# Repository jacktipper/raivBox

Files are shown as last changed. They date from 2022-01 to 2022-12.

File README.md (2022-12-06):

# raivBox

The raivBox is a standalone neural audio synthesis device based on Google Magenta's [DDSP](https://github.com/magenta/ddsp), with an [NVIDIA Jetson Nano 2GB](https://www.nvidia.com/en-us/autonomous-machines/embedded-systems/jetson-nano/education-projects/) embedded development board at its core. This entire project is designed to be as affordable and replicable as possible, while still offering a robust neural synthesis experience outside of a traditional laptop/desktop computer environment. 

[3D Model](https://a360.co/3CzAN5L)

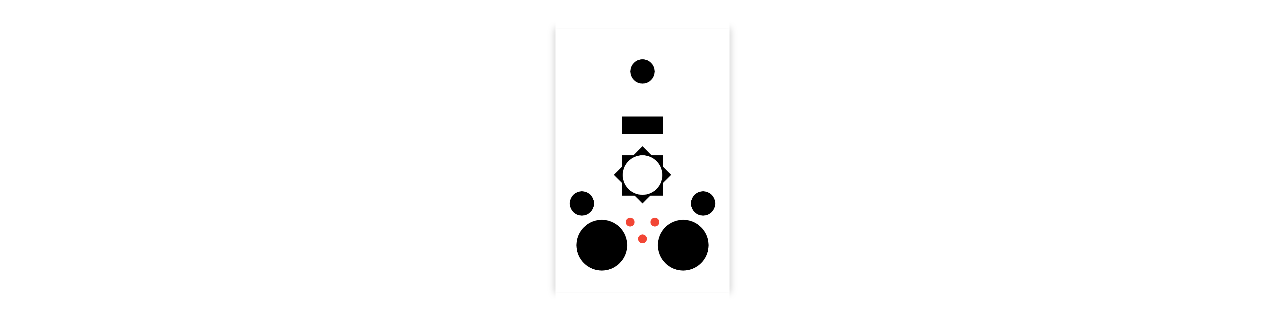
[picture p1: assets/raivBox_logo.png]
raivBox logo


## Abstract

Recent advances in deep learning-based audio creation are fueling the rise of a new approach to sound design: neural synthesis. Until now, robust neural synthesizers for musical sounds have been relegated to traditional desktop and cloud-based computing environments. Hosting these generative systems on low-cost devices will broaden offline and untethered access to this fledgling technology, helping to make way for a new era of modular music and audio experimentation. In this thesis, the implementation of neural waveform synthesis on a resource-limited embedded development platform is explored using a modified version of Google Magenta’s Differentiable Digital Signal Processing (DDSP) timbre transfer pipeline on an Nvidia Jetson Nano 2GB embedded prototyping board. Timbre transfer is a type of neural synthesis achieved by extracting audio features from an input signal and utilizing those data to generate a new waveform in the target timbre. This project introduces the raivBox: a functional neural synthesizer in the form of an affordable, standalone hardware product. It features a physical control interface that provides responsive audio input and output, a selection of five neural timbre models to choose from, and a straightforward user experience. The reworked neural synthesis pipeline demonstrates a significant processing latency reduction when compared with its predecessor, while maintaining similar sonic outputs. Qualitative research data indicate that users find the raivBox to be both intuitive and fun to interact with, and also suggest that it is perceived to be a valuable new tool for music creation and sound design. As this project is designed to be readily replicable by end users, the raivBox source code, build instructions, print files, and a variety of audio examples are all publicly available via its GitHub repository.

## Getting Started

Please refer to `assets/raivBox_thesis.pdf` for the full documentation of this project. See the *Methodology* section for detailed build instructions.

The `raivBox/` folder contains all of the important files and scripts.

To initialize a blank NVIDIA Jetson Nano 2GB operating system img with the required dependencies for this project, first flash the OS onto the Jetson, complete the basic user setup wizard, and then follow the instructions in the header of `raivBox/raivShell.sh`.

In later versions of this repository, a fully-baked OS img file will be provided. Flashing this img to a Jetson Nano 2GB's SD card will pre-load all of the software needed for this project.

The core DDSP synthesis loop is in `raivBox/synth.py`.

Useful system stats and UI animations are displayed via `raivBox/stats.py`.

All of the additional python files in this repository facilitate hardware-software interaction on the physical raivBox device.

In addition to the master's thesis document, the `assets/` folder contains the custom printed circuit board (PCB) zip file and the three stl files needed to 3D-print the raivBox housing components, as well as a few pictures and renders.

#

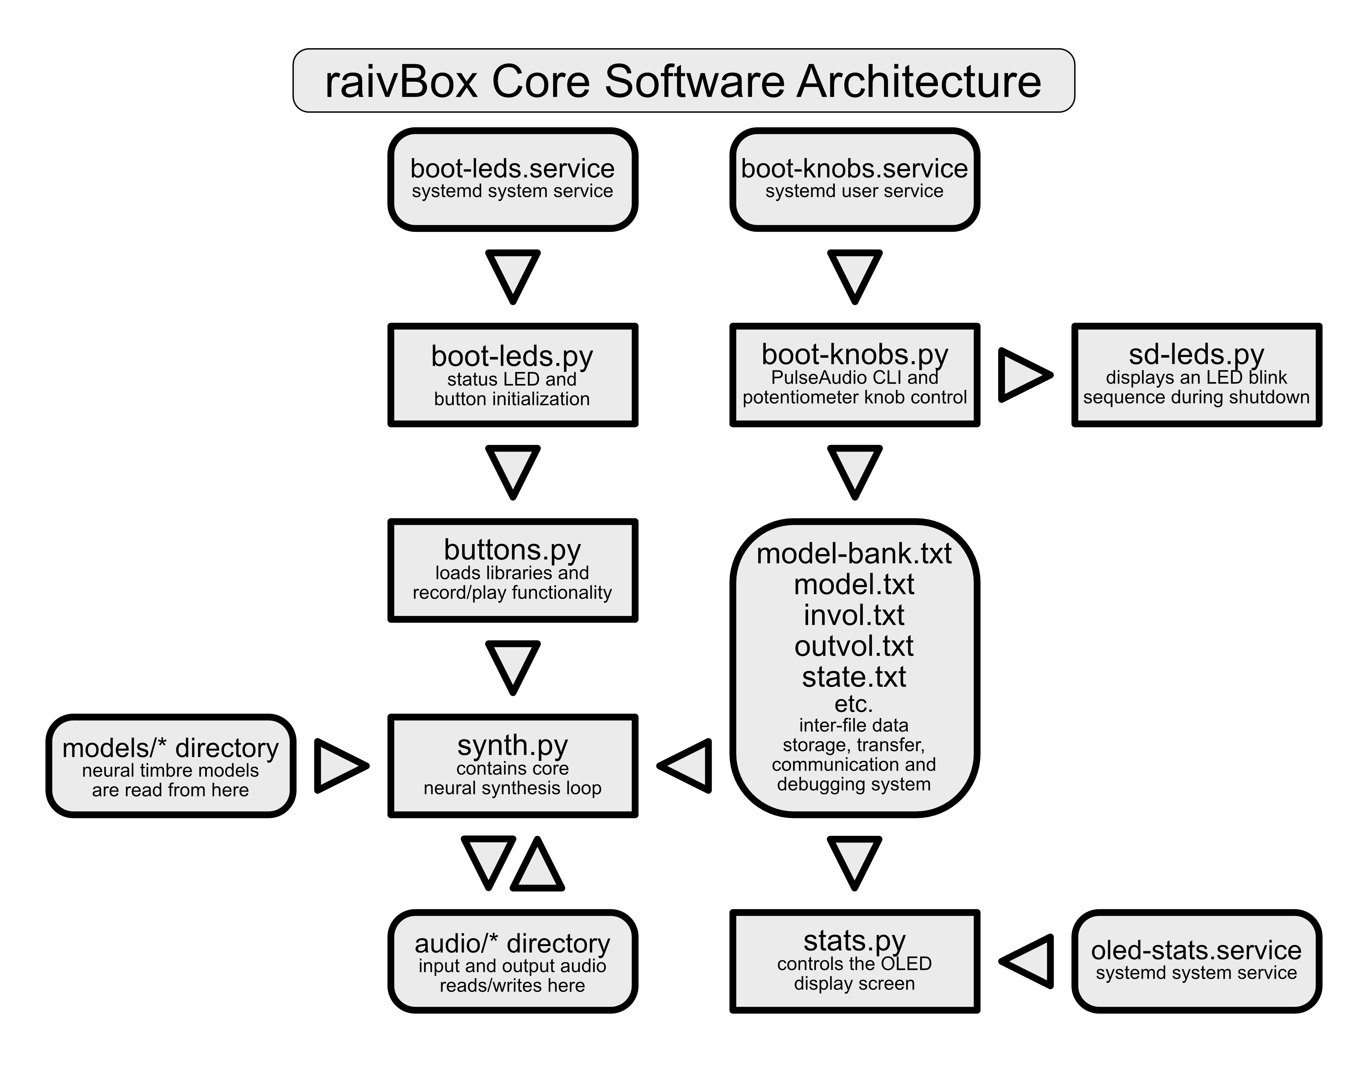
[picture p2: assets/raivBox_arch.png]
raivBox software architecture


#

### To replicate the basic functionality of this project, you will need:

• 1x NVIDIA Jetson Nano 2GB Embedded Development Kit

• 1x micro SD card (32GB+)

• 1x compatible USB-C power supply (https://www.canakit.com/raspberry-pi-4-power-supply.html)

• 1x Sabrent USB audio adapter (https://www.sabrent.com/product/AU-EMCB/usb-aluminum-external-stereo-sound-adapter-black/)

• 1x 3.5mm microphone (https://www.bhphotovideo.com/c/product/1632609-REG/boya_by_um4_3_5mm_mini_flexible_lavalier.html)

### For the optional housing and hardware control interface, you will also need:

• Access to a capable 3D-printer or 3D-printing service for the .stl files in the `assets/` folder

• Custom PCB manufacturing for `assets/raivBox_pcb.zip`

• 1x Adafruit PiOLED display (https://www.adafruit.com/product/3527)

• 1x compatible fan with hardware (https://smile.amazon.com/dp/B07YFDCGQV/ref=cm_sw_em_r_mt_dp_BDKKRKYSQ2KYJ76BYARS)

• 2x 2-pin 30mm arcade buttons (https://smile.amazon.com/gp/product/B005BZ421M/ref=ppx_yo_dt_b_search_asin_title?ie=UTF8&psc=1)

• 3x 10kΩ potentiometers (https://smile.amazon.com/gp/product/B07B64MWRF/ref=ppx_yo_dt_b_search_asin_title?ie=UTF8&psc=1)

• 3x standard 2-pin 5mm LEDs

• 1x MCP-3008 ADC IC chip

• 3x 220Ω resistors

• 2x 1kΩ resistors

• Plenty of M2.5 standoffs (https://smile.amazon.com/gp/product/B075K3QBMX/ref=ppx_yo_dt_b_search_asin_title?ie=UTF8&psc=1)

• Plenty of insulated wire (~28 gauge)

• Basic soldering tools and know-how

• 40-pin stacking header kit for PCB attachment

• 1x INIU USB-C power bank (https://smile.amazon.com/gp/product/B07CZDXDG8/ref=ppx_yo_dt_b_search_asin_title?ie=UTF8&psc=1)

• 1x short USB-C male to USB-C male cable

#

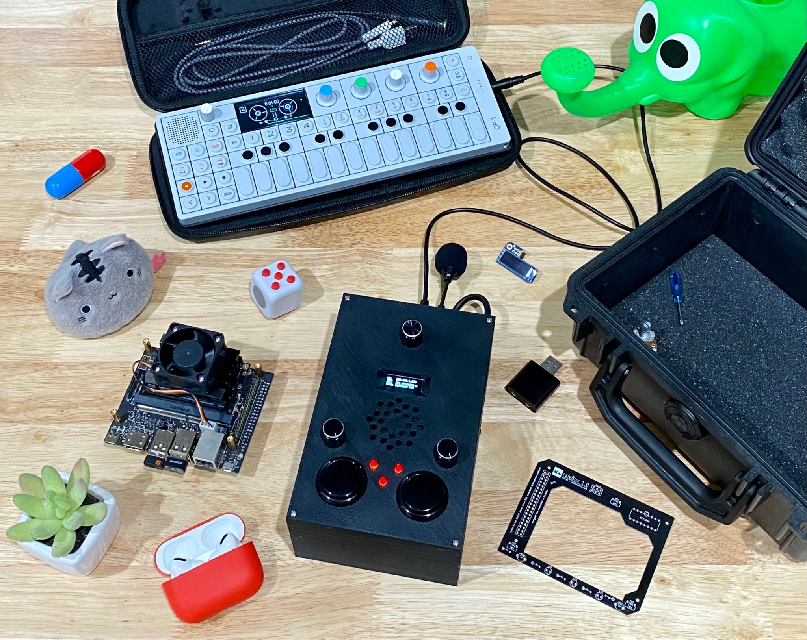
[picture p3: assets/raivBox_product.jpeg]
raivBox product


<!-- ![raivBox render](https://github.com/jacktipper/raivBox/blob/main/assets/raivBox_render.png) -->

#

### Disclaimer:

It should be noted that this project commenced in late 2020 and the bulk of the development occurred in early 2021. The literature review, comparisons, and aspects of the evaluation methodology are limited by the time and labor constraints of the master's thesis process, and would benefit from a thorough update and revision. Many recent developments in this field are relevant to improving this work, and should not be overlooked by others interested in this topic.

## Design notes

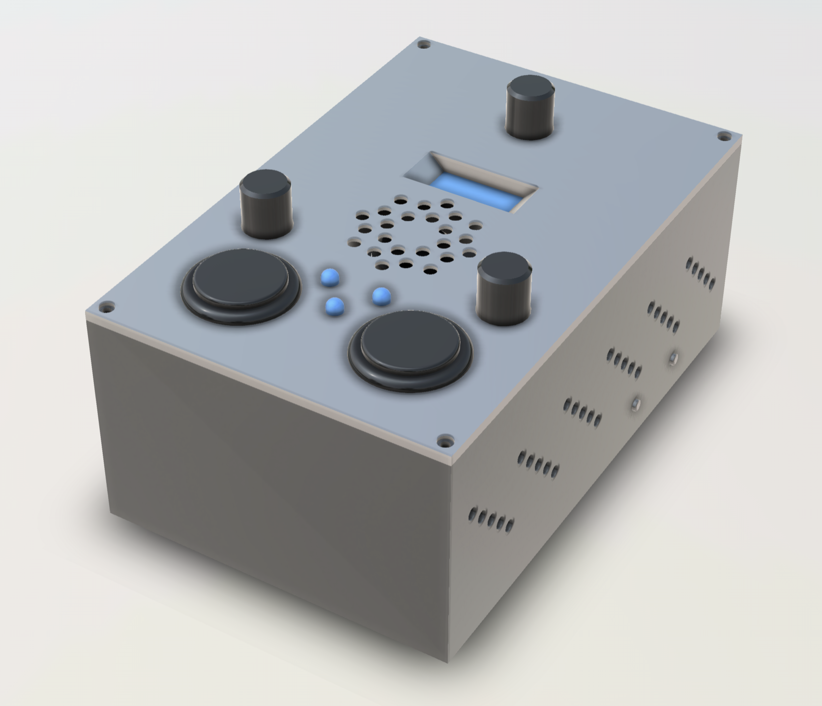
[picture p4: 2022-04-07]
assets/raivBox_render.png

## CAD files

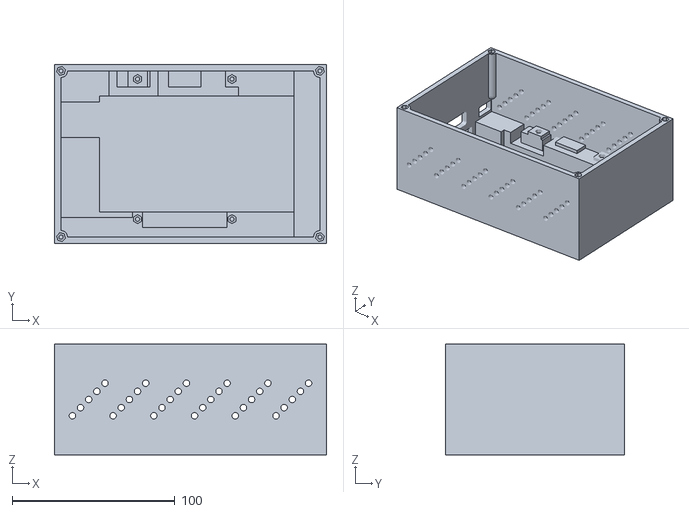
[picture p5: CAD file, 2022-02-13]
assets/housing.stl
167.0 x 110.0 x 68.0

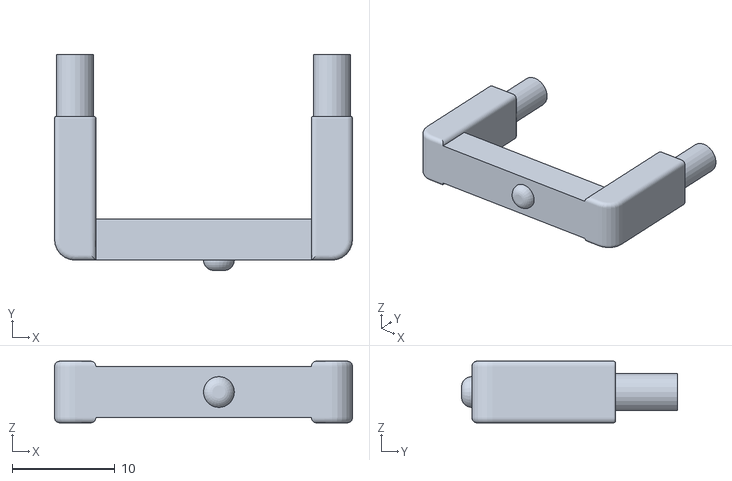
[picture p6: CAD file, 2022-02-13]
assets/power_plug.stl
29.0 x 21.0 x 6.00

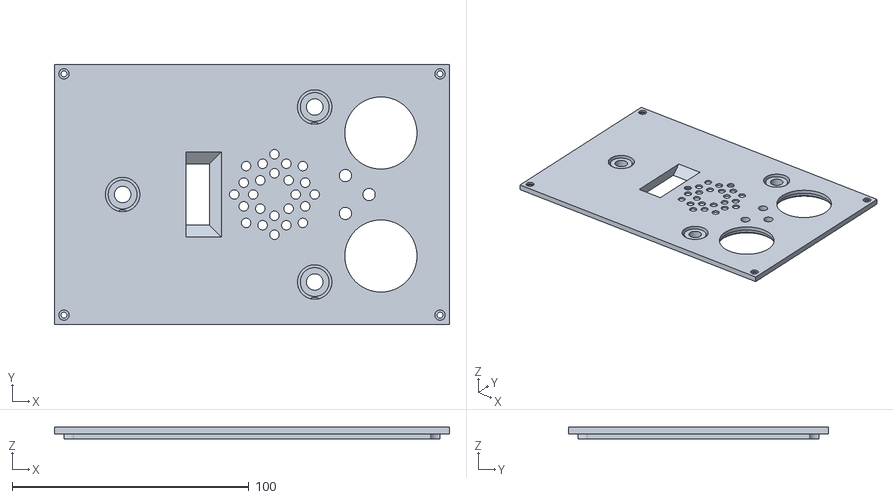
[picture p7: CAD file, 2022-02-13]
assets/faceplate.stl
167.0 x 110.0 x 5.00

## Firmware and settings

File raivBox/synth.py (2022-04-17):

# Portions copyright (c) 2022 RAIV - Jack Tipper
#
# Portions copyright (c) 2021 The DDSP Authors
#
# Licensed under the Apache License, Version 2.0 (the "License");
# you may not use this file except in compliance with the License.
# You may obtain a copy of the License at
#
#     http://www.apache.org/licenses/LICENSE-2.0
#
# Unless required by applicable law or agreed to in writing, software
# distributed under the License is distributed on an "AS IS" BASIS,
# WITHOUT WARRANTIES OR CONDITIONS OF ANY KIND, either express or implied.
# See the License for the specific language governing permissions and
# limitations under the License.

# Lint as: python3
"""Before importing libraries, set key hyperparameters for the neural synthesizer.
This is placed here at the top for user convenience when customizing.
"""
RATE = 16000  # Hz
VOICING_THRESHOLD = -125  # dB
PITCH_SHIFT = -1  # Octaves up or down
LOUDNESS = 5  # Loudness shift (similar to gain-staging; normalized anyway)
INPUT_PATH = 'audio/input.wav'
OUTPUT_PATH = 'audio/output.wav'

"""Import these first to fix the python environment and suppress warnings."""
import os
os.system('./init-py.sh')

import warnings
warnings.filterwarnings('ignore')


"""Import to start the LED blink sequence before time-consuming imports."""
import time
import Jetson.GPIO as GPIO
from multiprocessing import Process

GPIO.setmode(GPIO.BCM)
GPIO.setwarnings(False)
led0pin = 20
GPIO.setup(led0pin, GPIO.OUT, initial=GPIO.LOW)

def blinker():
    try:
        while True:
            GPIO.output(led0pin, GPIO.HIGH)
            time.sleep(0.08)
            GPIO.output(led0pin, GPIO.LOW)
            time.sleep(0.12)
    finally:
        GPIO.output(led0pin, GPIO.LOW)
    return

blink = Process(target=blinker)
blink.start()


"""Import heavy audio processing and deep learning libraries."""
import gin
import librosa
import pickle
import numpy as np
import soundfile as sf
import tensorflow.compat.v2 as tf
from ddsp.core import make_iterable, hz_to_midi, copy_if_tf_function
from ddsp.training.models import Autoencoder
from tensorflow.python.ops.numpy_ops import np_config
from datetime import datetime


"""Disable GPU inference (CUDA and TensorFlow need to be patched)."""
os.environ["CUDA_VISIBLE_DEVICES"] = "-1"


"""Create DDSP Helper Functions (extracted from official modules).
Changing these two hyperparameters is not recommended and may cause errors.
"""
LD_RANGE = 120.0  # dB
USE_TF = False  # tensorflow or numpy?


def squeeze(input_vector):
    """Ensure vector only has one axis of dimensionality."""
    if input_vector.ndim > 1:
        return np.squeeze(input_vector)
    else:
        return input_vector


def compute_audio_features(audio,
                           n_fft=2048,
                           sample_rate=RATE,
                           frame_rate=250):
    """Compute features from audio."""
    audio_feats = {'audio': audio}
    audio = squeeze(audio)

    audio_feats['loudness_db'] = compute_loudness(
        audio, sample_rate, frame_rate, n_fft)

    audio_feats['f0_hz'], audio_feats['f0_confidence'] = (
        compute_f0(audio, sample_rate, frame_rate))

    return audio_feats


def tf_float32(x):
    """Ensure array/tensor is a float32 tf.Tensor."""
    if isinstance(x, tf.Tensor):
        return tf.cast(x, dtype=tf.float32)  # This is a no-op if x is float32.
    else:
        return tf.convert_to_tensor(x, tf.float32)


def stft(audio, frame_size=2048, overlap=0.75, pad_end=True):
    """Differentiable stft in tensorflow, computed in batch."""
    assert frame_size * overlap % 2.0 == 0.0

    # Remove channel dim if present.
    audio = tf_float32(audio)
    if len(audio.shape) == 3:
        audio = tf.squeeze(audio, axis=-1)

    s = tf.signal.stft(
        signals=audio,
        frame_length=int(frame_size),
        frame_step=int(frame_size * (1.0 - overlap)),
        fft_length=int(frame_size),
        pad_end=pad_end)
    return s


def stft_np(audio, frame_size=2048, overlap=0.75, pad_end=True):
    """Non-differentiable stft using librosa, one example at a time."""
    assert frame_size * overlap % 2.0 == 0.0
    hop_size = int(frame_size * (1.0 - overlap))
    is_2d = (len(audio.shape) == 2)

    if pad_end:
        n_samples_initial = int(audio.shape[-1])
        n_frames = int(np.ceil(n_samples_initial / hop_size))
        n_samples_final = (n_frames - 1) * hop_size + frame_size
        pad = n_samples_final - n_samples_initial
        padding = ((0, 0), (0, pad)) if is_2d else ((0, pad),)
        audio = np.pad(audio, padding, 'constant')

    def stft_fn(y):
        return librosa.stft(y=y,
                            n_fft=int(frame_size),
                            hop_length=hop_size,
                            center=False).T

    s = np.stack([stft_fn(a) for a in audio]) if is_2d else stft_fn(audio)
    return s


def power_to_db(power, ref_db=0.0, range_db=LD_RANGE, use_tf=USE_TF):
    """Converts power from linear scale to decibels."""
    # Choose library.
    maximum = tf.maximum if use_tf else np.maximum
    log_base10 = log10 if use_tf else np.log10

    # Convert to decibels.
    pmin = 10**-(range_db / 10.0)
    power = maximum(pmin, power)
    db = 10.0 * log_base10(power)

    # Set dynamic range.
    db -= ref_db
    db = maximum(db, -range_db)
    return db
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

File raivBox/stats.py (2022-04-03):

#! /usr/bin/python3
# Portions copyright (c) 2022 RAIV
# Author: Jack Tipper
#
# Portions copyright (c) 2017 Adafruit Industries
# Authors: Tony DiCola & James DeVito
#
# Portions copyright (c) JetsonHacks 2019
#
# Portions copyright (c) NVIDIA 2019
#
# For portions copyright (c) 2022 RAIV - Jack Tipper:
# Licensed under the Apache License, Version 2.0 (the "License");
# you may not use this file except in compliance with the License.
# You may obtain a copy of the License at
#
#     http://www.apache.org/licenses/LICENSE-2.0
#
# Unless required by applicable law or agreed to in writing, software
# distributed under the License is distributed on an "AS IS" BASIS,
# WITHOUT WARRANTIES OR CONDITIONS OF ANY KIND, either express or implied.
# See the License for the specific language governing permissions and
# limitations under the License.
#
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
# Lint as: python3
"""Libraries and drivers."""
import time
import subprocess
import Adafruit_SSD1306  # This is the driver chip for the Adafruit PiOLED

from PIL import Image
from PIL import ImageDraw
from PIL import ImageFont


"""These functions assist in gathering data to display on the PiOLED."""
def get_network_interface_state(interface):
    return subprocess.check_output('cat /sys/class/net/%s/operstate' % interface, shell=True).decode('ascii')[:-1]


def get_ip_address(interface):
    if get_network_interface_state(interface) == 'down':
        return None
    cmd = "ifconfig %s | grep -Eo 'inet (addr:)?([0-9]*\.){3}[0-9]*' | grep -Eo '([0-9]*\.){3}[0-9]*' | grep -v '127.0.0.1'" % interface
    return subprocess.check_output(cmd, shell=True).decode('ascii')[:-1]


def get_cpu_usage():
    """Note: This CPU usage function doesn't work as intended yet."""
    # Shell scripts for system monitoring from here: 
    # https://unix.stackexchange.com/questions/119126/command-to-display-memory-usage-disk-usage-and-cpu-load
    cmd = "awk '{u=$2+$4; t=$2+$4+$5; if (NR==1){u1=u; t1=t;} else print ($2+$4-u1) * 100 / (t-t1) \"%\"; }' \
           <(grep 'cpu ' /proc/stat) <(sleep 0.16;grep 'cpu ' /proc/stat)"
    CPU = float(subprocess.check_output(cmd, shell=True).decode('ascii')[:-3])
    return CPU


def get_gpu_usage():
    GPU = 0.0
    with open("/sys/devices/gpu.0/load", encoding="utf-8") as gpu_file:
        GPU = gpu_file.readline()
        GPU = int(GPU)/10
    return GPU


"""The display is 128x32 pixels, with hardware I2C.
Setting gpio to 1 is hack to avoid platform detection.
"""
disp = Adafruit_SSD1306.SSD1306_128_32(rst=None, i2c_bus=1, gpio=1)


# Initialize library.
disp.begin()

# Clear display.
disp.clear()
disp.display()

# Create blank image for drawing.
# Make sure to create image with mode '1' for 1-bit color.
width = disp.width
height = disp.height
image = Image.new('1', (width, height))

# Get drawing object to draw on image.
draw = ImageDraw.Draw(image)

# Draw a black filled box to clear the image.
draw.rectangle((0, 0, width, height), outline=0, fill=0)

# Define some constants to allow easy resizing of shapes.
padding = -2
top = padding
bottom = height-padding

# Move left to right keeping track of the current x position for drawing shapes.
x = 0

# Load default font.
font = ImageFont.load_default()


"""During the initial boot-up sequence of the raivBox, display an ASCII animation."""
booting = True
while booting:
    draw.rectangle((0, 0, width, height), outline=0, fill=0)
    draw.text((x, top),    "                      ", font=font, fill=255)
    draw.text((x, top+8),  "     R A I V B O X    ", font=font, fill=255)
    draw.text((x, top+16), "                      ", font=font, fill=255)
    draw.text((x, top+25), "                      ", font=font, fill=255)
    disp.image(image)
    disp.display()
    time.sleep(1.14)
    draw.rectangle((0, 0, width, height), outline=0, fill=0)
    disp.image(image)
    disp.display()
    time.sleep(0.06)
    draw.rectangle((0, 0, width, height), outline=0, fill=0)
    draw.text((x, top),    "x                     ", font=font, fill=255)
    draw.text((x, top+8),  "                      ", font=font, fill=255)
    draw.text((x, top+16), "                      ", font=font, fill=255)
    draw.text((x, top+25), "                      ", font=font, fill=255)
    disp.image(image)
    disp.display()
    time.sleep(0.04)
    draw.rectangle((0, 0, width, height), outline=0, fill=0)
    draw.text((x, top),    "ox                    ", font=font, fill=255)
    draw.text((x, top+8),  "x                     ", font=font, fill=255)
    draw.text((x, top+16), "                      ", font=font, fill=255)
    draw.text((x, top+25), "                      ", font=font, fill=255)
    disp.image(image)
    disp.display()
    time.sleep(0.04)
    draw.rectangle((0, 0, width, height), outline=0, fill=0)
    draw.text((x, top),    "Box                   ", font=font, fill=255)
    draw.text((x, top+8),  "ox                    ", font=font, fill=255)
    draw.text((x, top+16), "x                     ", font=font, fill=255)
    draw.text((x, top+25), "                      ", font=font, fill=255)
    disp.image(image)
    disp.display()
    time.sleep(0.04)
    draw.rectangle((0, 0, width, height), outline=0, fill=0)
    draw.text((x, top),    "vBox                  ", font=font, fill=255)
    draw.text((x, top+8),  "Box                   ", font=font, fill=255)
    draw.text((x, top+16), "ox                    ", font=font, fill=255)
    draw.text((x, top+25), "x                     ", font=font, fill=255)
    disp.image(image)
    disp.display()
    time.sleep(0.04)
    draw.rectangle((0, 0, width, height), outline=0, fill=0)
    draw.text((x, top),    "ivBox                 ", font=font, fill=255)
    draw.text((x, top+8),  "vBox                  ", font=font, fill=255)
    draw.text((x, top+16), "Box                   ", font=font, fill=255)
    draw.text((x, top+25), "ox                    ", font=font, fill=255)
    disp.image(image)
    disp.display()
    time.sleep(0.04)
    draw.rectangle((0, 0, width, height), outline=0, fill=0)
    draw.text((x, top),    "aivBox                ", font=font, fill=255)
    draw.text((x, top+8),  "ivBox                 ", font=font, fill=255)
    draw.text((x, top+16), "vBox                  ", font=font, fill=255)
    draw.text((x, top+25), "Box                   ", font=font, fill=255)
    disp.image(image)
    disp.display()
    time.sleep(0.04)
    draw.rectangle((0, 0, width, height), outline=0, fill=0)
    draw.text((x, top),    "raivBox               ", font=font, fill=255)
    draw.text((x, top+8),  "aivBox                ", font=font, fill=255)
    draw.text((x, top+16), "ivBox                 ", font=font, fill=255)
    draw.text((x, top+25), "vBox                  ", font=font, fill=255)
    disp.image(image)
    disp.display()
    time.sleep(0.04)
    draw.rectangle((0, 0, width, height), outline=0, fill=0)
    draw.text((x, top),    " raivBox              ", font=font, fill=255)
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

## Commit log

2022-01-31 Upload logo
    [piano_sev.f0.csv]
2022-02-06 Complete file restructure
    [piano_sev.f0.csv]
2022-02-13 3d housing .stl files
    [faceplate.stl, housing.stl, power_plug.stl]

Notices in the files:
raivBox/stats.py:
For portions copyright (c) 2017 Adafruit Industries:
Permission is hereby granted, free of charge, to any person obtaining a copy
